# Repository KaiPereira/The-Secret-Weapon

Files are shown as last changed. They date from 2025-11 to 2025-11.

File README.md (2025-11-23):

Frame 1(7)

# The Secret Weapon Information

You've been tasked with building the secret weapon, your goal is simple: Help build the largest collaborative PCB alongside 100 other highschoolers!

**Try to read all of this before adding something to the board, it's important information!**

First off, all the submissions will get 25 tickets, and 10% prototype progress! If you add something really, really cool, I might be able to hand out more tickets, but submit your component, before asking me!

Submission is as simple as this:

* Put your name down for what schematic sheet you're working on (so we don't have merge conflicts) in the canvas in #The-Secret-Weapon on Slack! If you don't want to be on Slack, you can probably work backwards in the sheets, like start at 100 or something!
* Fork/clone the repository
* Go into the schematic sheet you put yourself down for and rename it to your name + what you're working on!
* Wire up your component in the schematic (don't mess with other people's schematics without specific permission, unless they've added like an MCU or something), please don't add components that costs more than $5, so that we can get this thing made hopefully affordably!
* Route your component, make sure to have clean routing so that you don't take up too much space on the board! Also follow the routing guidelines that I listed in the PCB stackup information down below
* Commit the changes to your forked repository and open up a pull request!

I've added the root power system, it has 3 rails:

* 12V, 15A - Large components, high current/voltage, keep trace thick to high current stuff
* 5V, 4 - 5A - Medium currents, mid current/voltage, keep traces decently thick for mid current stuff
* 3V3. 1.5A - Low level systems, low current/voltage, don't use too much current on this layer

L3 is a 3V3 power fill, so you can just use a via to get down to it. If you need 5V or 12V, route it on the power layer, and then via up to use it!

The PCB stackup (how the layers are organized) is:

* TOP/SIGNAL  - Use this for routing!!! Put components on it too!
* GND - DON'T ROUTE ANYTHING ON THIS LAYER, if you need analog/split ground know what you're doing.
* PWR - Only route power stuff on this layer, and try to keep it clean
* SIGNAL - High speed routing if anyone wants, try to use the top and bottom and only use this if you need to
* GND - DON'T ROUTE ANYTHING ON THIS LAYER, if you need analog ground/split know what you're doing.
* BOTTOM/SIGNAL - Use this for routing!!! Don't put components on it though, but you're free to add silkscreen to it!

If any of your components need power or ground, you can just put a via down to either the ground or power layers. You can see how I did this with the TMC2209 stepstick driver I added in the very top left of the board!

Let's embrace the chaos, but try to make sure that whatever you're doing is actually wired/routed properly so we don't ruin the board for everyone else. When you make your PR, I might modify it a bit to work properly if I see something that's wrong, and it might also need to be re-routed if I'm behind on merging PR's! Also run DRC and check your part of the PCB, I'll also be fixing some of these if need be.

Try also not to add anything crazy big that takes up like a quarter for the board, or something that intentionally hoards power all the time, keep everyone else in mind with your components! Try to keep your components to like one big thing, and then you can add like decoupling, passives, etc. If there's no more I/O's left, you'll need to add an MCU, or wait for someone else to add one! Also try to add the manufacturer numbers, you can fine this under MFR.Part # on JLC/LCSC, for example https://jlcpcb.com/partdetail/471340-TMC2209LA/C465949 is TMC2209-LA!

Try not to move other people's pins around on the MCU's, or mess with the root systems unless you know what you're doing, some people need specific peripherals!

If you need any help, or to verify anything, feel free to put it in this channel and someone will definitely help!

Also feel free to customize your schematic sheet by adding text, and also add some cool silkscreen or drawings underneath your components.

**PLEASE KEEP ALL COMPONENTS TO THE TOP LAYER**, we want to make our board easily manufacturable and there's very few things that need components on both sides.

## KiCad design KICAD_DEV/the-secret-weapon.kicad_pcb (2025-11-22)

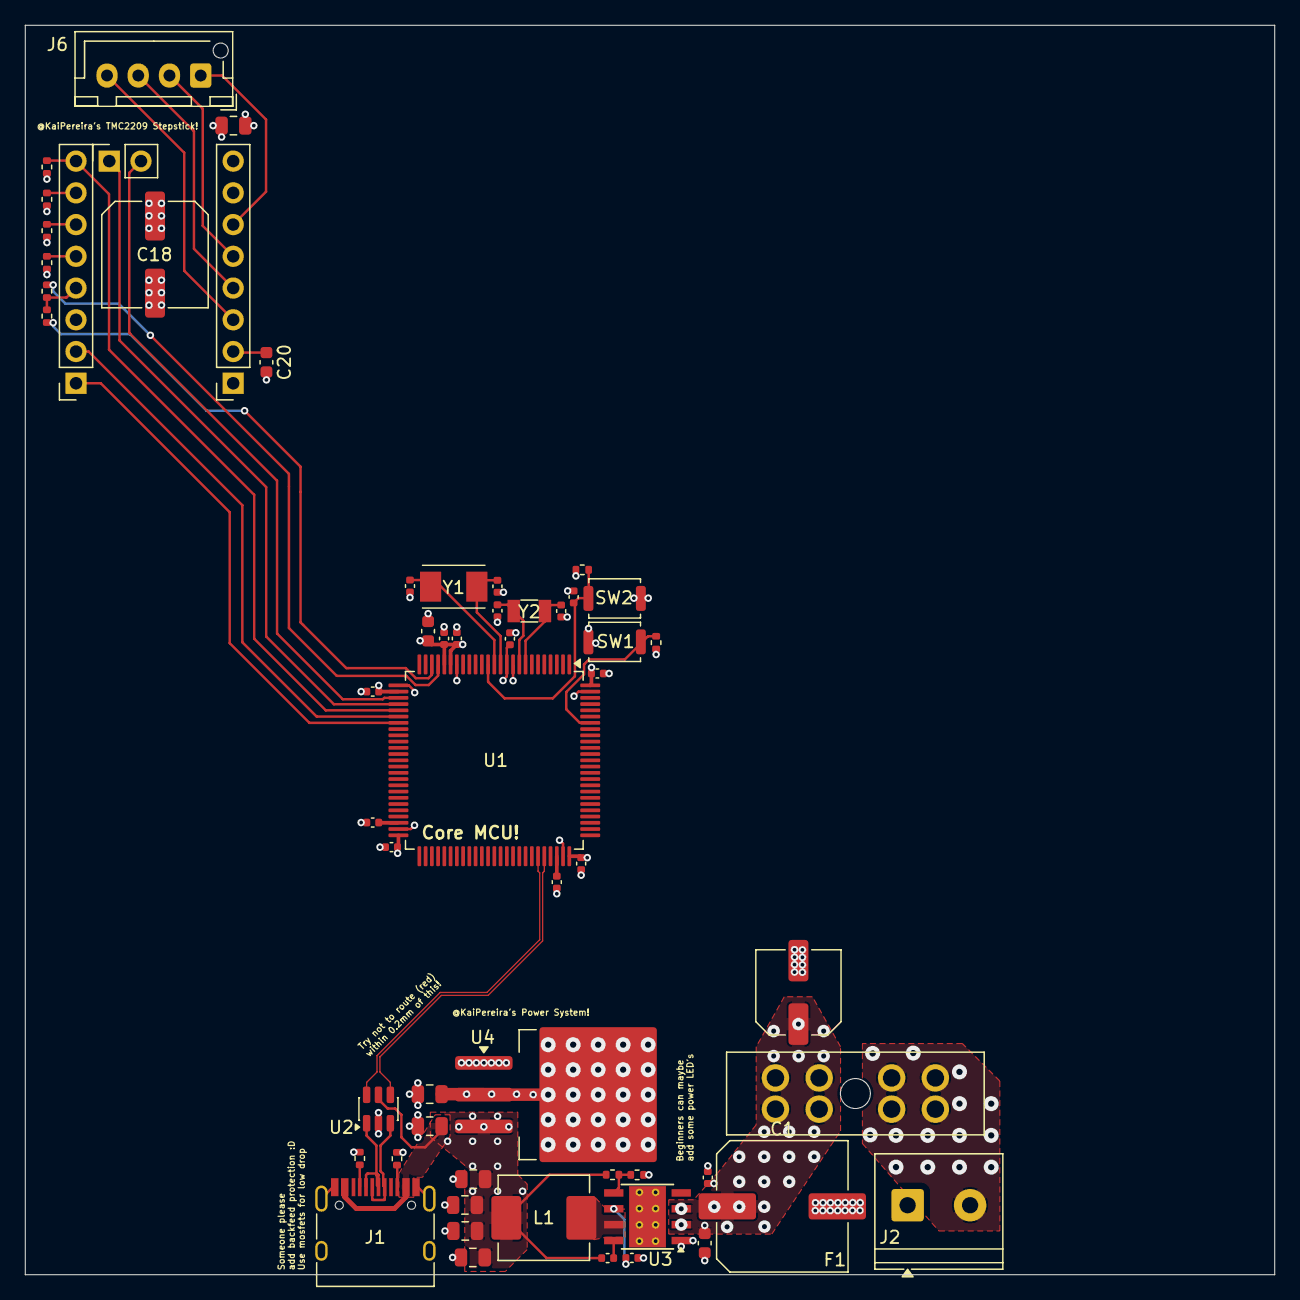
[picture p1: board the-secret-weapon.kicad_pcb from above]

Board: 6 copper layers, 100.0 x 100.0 mm, 58 parts (0 on the bottom side), 38 nets.

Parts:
C1: 1000uF; C_Elec_10x10.2
C2: 220nF; C_0402_1005Metric
C3: 10uF; C_0603_1608Metric
C4, C10, C17, C21, C23, C24, C25, C26, C27: 0.1uF; C_0402_1005Metric
C5, C6, C11, C12, C15: 22uF; C_0805_2012Metric
C7, C8: 2.2uF; C_0402_1005Metric
C9: 4.7uF; C_0603_1608Metric
C13: 1uF; C_0402_1005Metric
C14: 10uF; C_0805_2012Metric
C16: 100uF; C_Elec_6.3x5.8
C18: 220uF; C_Elec_8x6.2
C19: 0.1uF; C_0805_2012Metric
C20: 0.1uF; C_0603_1608Metric
C28, C29: 32pF; C_0402_1005Metric
C30, C31: 17pF; C_0402_1005Metric
F1: 20A; FuseHolder_Blade_ATO_Littelfuse_FLR_178.6165
J1: USB_C_Receptacle_USB2.0_14P; USB_C_Receptacle_HRO_TYPE-C-31-M-12
J2: Screw_Terminal_01x02; TerminalBlock_Phoenix_PT-1,5-2-5.0-H_1x02_P5.00mm_Horizontal
J3, J4: Conn_01x08; PinSocket_1x08_P2.54mm_Vertical
J5: Conn_01x02; PinSocket_1x02_P2.54mm_Vertical
J6: Conn_01x04; JST_XH_B4B-XH-AM_1x04_P2.50mm_Vertical
L1: 6.8uH; L_TechFuse_SL0650
R1, R2: 5.1K; R_0402_1005Metric
R3: 100K; R_0402_1005Metric
R4: 24.9K; R_0402_1005Metric
R5, R6: 1K; R_0402_1005Metric
R7, R8, R9, R10, R13, R14: 10K; R_0402_1005Metric
SW1, SW2: SW_Push; SW_Push_SPST_NO_Alps_SKRK
U1: STM32H743VITx; LQFP-100_14x14mm_P0.5mm
U2: USBLC6-2SC6; SOT-23-6
U3: LMR33640ADDA; Texas_HSOP-8-1EP_3.9x4.9mm_P1.27mm_ThermalVias
U4: LM1086S-3.3/TR; TO-263-3_TabPin2
Y1: 8 MHz; Crystal_SMD_TXC_7A-2Pin_5x3.2mm
Y2: 32.768 KHz; Crystal_SMD_3215-2Pin_3.2x1.5mm

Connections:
+3V3: C9.1, C10.1, C15.1, C17.1, C20.1, C21.1, C23.1, C24.1, C25.1, C26.1, J4.2, R10.1, R13.1, SW2.1, U1.11 (VDD), U1.20 (VREF+), U1.21 (VDDA), U1.27 (VDD), U1.50 (VDD), U1.75 (VDD), U1.100 (VDD), U4.2 (VO)
+5V: C4.2, C5.1, C6.1, C11.1, C12.1, C14.1, J1.A4 (VBUS), J1.A9 (VBUS), J1.B4 (VBUS), J1.B9 (VBUS), L1.2, R3.1, U2.5 (VBUS), U4.3 (VI)
+12V: C1.1, C2.1, C3.1, C16.1, C18.1, C19.1, F1.2, J4.8, U3.2 (VIN), U3.3 (EN)
BOOT: R14.1, SW2.2, U1.94 (BOOT0)
D+: U1.71 (PA12), U2.4 (I/O2)
D-: U1.70 (PA11), U2.6 (I/O1)
GND: C1.2, C2.2, C3.2, C5.2, C6.2, C7.2, C8.2, C9.2, C10.2, C11.2, C12.2, C13.2, C14.2, C15.2, C16.2, C17.2, C18.2, C19.2, C20.2, C21.2, C23.2, C24.2, C25.2, C26.2, C27.2, C28.2, C29.2, C30.2, C31.2, J1.A1 (GND), J1.A12 (GND), J1.B1 (GND), J1.B12 (GND), J1.S1 (SHIELD), J2.1, J4.1, J4.7, R1.2, R2.2, R4.2, R7.2, R8.2, R9.2, R14.2, SW1.1, U1.10 (VSS), U1.19 (VSSA), U1.26 (VSS), U1.49 (VSS), U1.74 (VSS), U1.99 (VSS), U2.2 (GND), U3.1 (GND), U3.9 (GND), U4.1 (GND)
unnamed: C7.1, U1.73 (VCAP)
unnamed: C8.1, U1.48 (VCAP)
unnamed: J1.A5 (CC1), R1.1
unnamed: J1.B5 (CC2), R2.1
unnamed: F1.1, J2.2
unnamed: J3.4, R5.1, R6.2
unnamed: J3.5, R7.1
unnamed: J3.6, R8.1
unnamed: J3.7, R9.1
unnamed: J4.3, J6.4
unnamed: J4.4, J6.3
unnamed: J4.5, J6.2
unnamed: J4.6, J6.1
unnamed: L1.1, U3.7 (BOOT)
unnamed: R3.2, R4.1, U3.5 (FB)
unnamed: C4.1, U3.8 (SW)
unnamed: C13.1, U3.6 (VCC)
OSC32_IN: C30.1, U1.8 (PC14), Y2.2
OSC32_OUT: C31.1, U1.9 (PC15), Y2.1
OSC_IN: C28.1, U1.12 (PH0), Y1.2
OSC_OUT: C29.1, U1.13 (PH1), Y1.1
RESET: C27.1, R13.2, SW1.2, U1.14 (NRST)
TMC2209_DIAG: J5.1, U1.29 (PA5)
TMC2209_DIR: J3.1, U1.32 (PC4)
TMC2209_EN: J3.8, R10.2, U1.30 (PA6)
TMC2209_INDEX: J5.2, U1.28 (PA4)
TMC2209_RX: R5.2, U1.23 (PA1)
TMC2209_STEP: J3.2, U1.31 (PA7)
TMC2209_TX: R6.1, U1.22 (PA0)
USB_D+: J1.A6 (D+), J1.B6 (D+), U2.3 (I/O2)
USB_D-: J1.A7 (D-), J1.B7 (D-), U2.1 (I/O1)

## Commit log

2025-10-22 init the PCB
    [the-secret-weapon.kicad_pcb, the-secret-weapon.kicad_sch]
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2025-10-22 Update README with project details and instructions
    Added introductory text about the collaborative PCB project.
2025-10-22 adding layer stackup of SIGNAL/GND/PWR/SIGNAL/GND/SIGNAL
    [the-secret-weapon.kicad_pcb]
2025-10-22 ground pour + core SoC STM32H757
    [the-secret-weapon.kicad_pcb, the-secret-weapon.kicad_sch]
2025-10-22 accidently used the wrong symbol
    [the-secret-weapon.kicad_pcb, the-secret-weapon.kicad_sch]
2025-10-24 working on USB PD
    [the-secret-weapon.kicad_sch]
2025-10-24 adding my custom USB PD symbol
    [the-secret-weapon.kicad_sch]
2025-10-24 revising my USB PD
    [the-secret-weapon.kicad_sch]
2025-10-24 wiring USB-C
    [the-secret-weapon.kicad_sch]
2025-10-25 starting to wire ESD
    [the-secret-weapon.kicad_sch]
2025-10-25 more USB-C stuff
    [the-secret-weapon.kicad_sch]
2025-10-25 finished wiring USB ESD protection
    [the-secret-weapon.kicad_sch]
2025-10-25 starting to wire my USB PD
    [the-secret-weapon.kicad_sch]
2025-10-25 more progress on USB PD
    [the-secret-weapon.kicad_sch]
2025-10-26 almost done USB PD wiring (this is a lie)
    [USB-C-PD.kicad_sch, the-secret-weapon.kicad_sch]
2025-10-27 pretty much done USB-PD wiring, just gotta do GPIO's
    [USB-C-PD.kicad_sch]
2025-10-28 some school shenanigans
    [brain-mcu.kicad_sch, the-secret-weapon.kicad_sch]
2025-10-29 some decoupling and organization
    [brain-mcu.kicad_sch]
2025-11-14 working on submission
    [USB-C-PD.kicad_sch]
2025-11-14 changing the MCU for more chaos
    [brain-mcu.kicad_sch]
2025-11-14 decoupling caps, vref, and vcap
    [brain-mcu.kicad_sch]
2025-11-14 NRST and cleaner schematic
    [brain-mcu.kicad_sch]
2025-11-14 more cleaning up and adding boot
    [brain-mcu.kicad_sch]
2025-11-15 updating some stuff
    [USB-C-PD.kicad_sch, the-secret-weapon.kicad_pcb]
2025-11-17 added the boot button
    [brain-mcu.kicad_sch]
2025-11-17 adding the 8mhz crystal
    [brain-mcu.kicad_sch]
2025-11-17 adding the 32.768KHz crystal!
    [brain-mcu.kicad_sch]
2025-11-18 cleaning stuff up!
    [brain-mcu.kicad_sch]
2025-11-18 switching to a PSU
    [USB-C-PD.kicad_sch]
2025-11-18 ESD Protection!
    [USB-C-PD.kicad_sch]
2025-11-18 some more progress
    [the-secret-weapon.kicad_pcb]
2025-11-19 working on the buck converter!
    [power.kicad_sch, the-secret-weapon.kicad_sch]
2025-11-19 finished buck converter wiring!
    [power.kicad_sch]
2025-11-19 added all the basic footprints!
    [brain-mcu.kicad_sch, power.kicad_sch]
2025-11-19 assigning more footprints!g
    [USB-C-PD.kicad_sch, brain-mcu.kicad_sch, power.kicad_sch]
2025-11-19 all footprints are in!
    [power.kicad_sch]
2025-11-19 added in the 1.5A 3V3 LDO!
    [power.kicad_sch]
2025-11-19 cleaning up the schematic, adding some footnotes for contributors!
    [brain-mcu.kicad_sch, power.kicad_sch]
2025-11-19 starting the actual board!
    [power.kicad_sch, the-secret-weapon.kicad_pcb]
2025-11-20 starting the layout of my power system!
    [the-secret-weapon.kicad_pcb]
2025-11-20 an absolutely gorgeous power layoutgit add .
    [the-secret-weapon.kicad_pcb]
2025-11-20 changing cap size, but it's probably not adequate
    [power.kicad_sch, the-secret-weapon.kicad_pcb]
2025-11-20 heading to school!
    [power.kicad_sch, the-secret-weapon.kicad_pcb]
2025-11-20 grounding and working on power, added the 100uF cap
    [power.kicad_sch, the-secret-weapon.kicad_pcb]
2025-11-20 adding the power fills
    [the-secret-weapon.kicad_pcb]
2025-11-21 working on some more routing!
    [the-secret-weapon.kicad_pcb]
2025-11-21 finished routing the power!
    [power.kicad_sch, the-secret-weapon.kicad_pcb]
2025-11-21 layed out the main SoC
    [the-secret-weapon.kicad_pcb]
2025-11-21 routed the SoC!
    [brain-mcu.kicad_sch, the-secret-weapon.kicad_pcb]
2025-11-21 finished power routing, just have to add the power rails now!
    [the-secret-weapon.kicad_pcb]
2025-11-21 adjusting the power fills and adding the power rails!
    [the-secret-weapon.kicad_pcb]
2025-11-21 forgot to wire USB data pairs, doing that now!
    [brain-mcu.kicad_sch, power.kicad_sch, the-secret-weapon.kicad_pcb]
2025-11-21 added some more warnings around the board and routed the USB data pairs!
    [the-secret-weapon.kicad_pcb]
2025-11-21 done with the root PCBgit add .
    [the-secret-weapon.kicad_pcb]
2025-11-21 added all 150 hierarchial sheets!
    [1.kicad_sch, 10.kicad_sch, 100.kicad_sch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]
2025-11-21 adding some instructions inside of the schematic!
    [the-secret-weapon.kicad_pcb, the-secret-weapon.kicad_sch]
2025-11-21 wired my TMC2209 :D
    [1.kicad_sch, the-secret-weapon.kicad_sch]
2025-11-21 wired the TMC2209 to my MCU, also more instructions on the schematic!
    [brain-mcu.kicad_sch, power.kicad_sch]
2025-11-22 layed out all the components
    [1.kicad_sch, the-secret-weapon.kicad_pcb]
2025-11-22 working on routing my TMC2209 driver!
    [the-secret-weapon.kicad_pcb]
2025-11-22 finished routing my TMC2209 motor driver!
    [brain-mcu.kicad_sch, the-secret-weapon.kicad_pcb]
